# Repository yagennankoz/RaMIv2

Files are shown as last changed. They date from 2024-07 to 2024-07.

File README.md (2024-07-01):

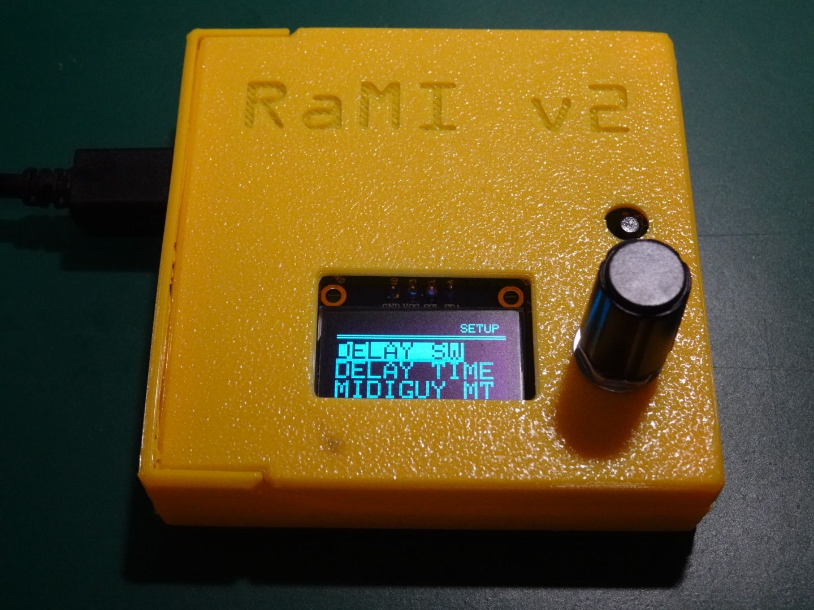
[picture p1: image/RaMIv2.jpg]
RaMI v2

# RaMI v2
X68000 Z MIDIインターフェイス<br>
MIDIタイミング遅延機能<br>
MIDI野郎 強制MT32音色機能付き<br>
<br>
<br>
### インストール方法
RaspberryPi picoのBOOTSELボタンを押しながらPCとUSB接続してください。<br>
Winの場合、エクスプローラで立ち上がってきますので、firmwareフォルダのfirmware.uf2をコピーしてください。<br>
ファイルのコピーが完了するとpicoが再起動します。<br>

### 操作方法
ロータリーエンコーダで選択および決定。タクトスイッチはキャンセルボタンです。<br>
決定/キャンセルボタン押下でメニューが表示されます。<br>
<br>
- DELAY SW
  - MIDI遅延のON/OFF
- DELAY TIME
  - MIDI遅延時間設定
- MIDIGUY MT
  - MIDI野郎音色のMT32互換モードON/OFF
- RESET
  - 設定の初期化

### 開発環境
- PlatformIO

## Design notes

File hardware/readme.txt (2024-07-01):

RaMI v2ボード  ver.0.2

回路図、ガーバー等のセットです。
一応お断りしておきますが、この回路を使用してX68000ZやRaspberryPi pico、MIDI音源等が破損しても当方は一切責任を負えませんのであらかじめご了承ください。

使用パーツは以下です。

・UART端子
	ターミナルブロック レセプタクル 2.54mm 3P
	[WJ15EDGRC-2.54-03P-140-00A]
	
	秋月電子
		https://akizukidenshi.com/catalog/g/gP-17009/

・ロータリーエンコーダ
	uxcell 360度ロータリーエンコーダ 7ピン 20桁 スイッチ付き
	
	Amazon
		https://www.amazon.co.jp/gp/product/B07RN3HB25/ref=ppx_yo_dt_b_asin_title_o08_s00

・3.5mm TRS
	3.5ｍｍ小型ステレオミニジャック 基板取付用

	秋月電子
		https://akizukidenshi.com/catalog/g/gC-02460/

・タクトスイッチ
	秋月電子
		https://akizukidenshi.com/catalog/g/gP-03646/

・OLED
	ピン配列がGND/VCC/SCL/SDAのSSD1306モジュール

	Amazon
		https://www.amazon.co.jp/gp/product/B08CDGTBCG/ref=ppx_yo_dt_b_asin_title_o03_s00

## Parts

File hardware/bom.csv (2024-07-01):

Designator | Footprint | Quantity | Value | LCSC Part #
Brd1 | 128x64OLED | 1 | SSD1306
C1, C2 | 0603 | 2 | 0.01u
J2 | Jack_3.5mm_Switronic_ST-005-G_horizontal | 1 | TRS
R1 | 0603 | 1 | 33 | C23140
R2 | 0603 | 1 | 10 | C22859
R3 | 0603 | 1 | 3.3k | C22978
R4, R5, R6, R7, R8 | 0603 | 5 | 10k | C25804
SW1 | RotaryEncoder_Alps_EC12E-Switch_Vertical_H20mm | 1 | RotaryEncoder_Switch
SW2 | SW_PUSH_6mm | 1 | SW_Push
U2 | RPi_Pico_SMD_TH | 1 | Pico
UART1 | WJ15EDGRC-2.54-03P-140-00A | 1 | ~

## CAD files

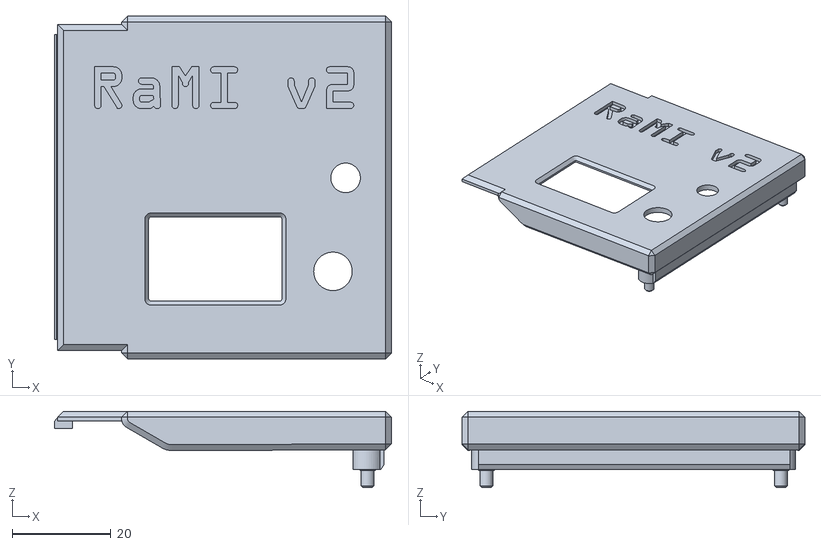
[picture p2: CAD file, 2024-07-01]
case/RaMI2_TOP.stl
68.3 x 69.5 x 15.5

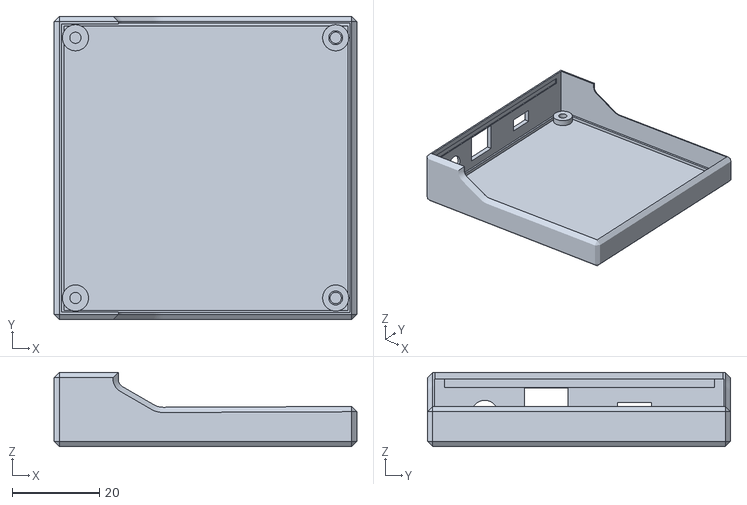
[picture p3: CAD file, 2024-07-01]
case/RaMI2_BOTTOM.stl
69.4 x 69.5 x 17.0

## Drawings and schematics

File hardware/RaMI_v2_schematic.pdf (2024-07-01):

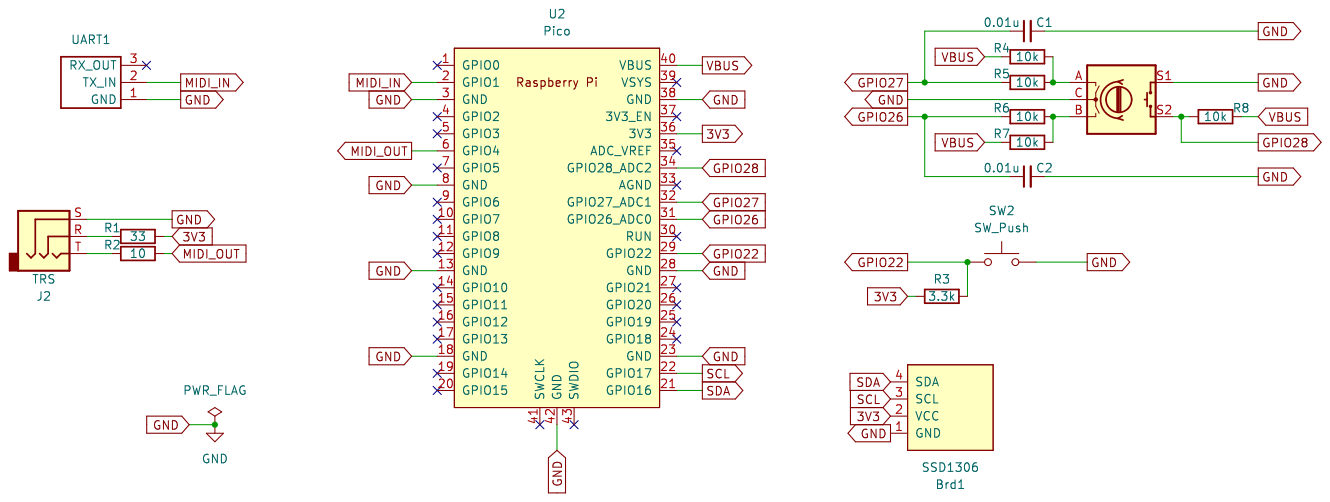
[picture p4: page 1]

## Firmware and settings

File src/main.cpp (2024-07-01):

#include <Arduino.h>

#include <stdio.h>
#include <string.h>
#include <hardware/uart.h>
#include <hardware/gpio.h>
#include <SPI.h>
#include <Wire.h>
#include <Adafruit_GFX.h>
#include <Adafruit_SSD1306.h>

#include "ModeBase.hpp"
#include "ModePlay.hpp"
#include "ModeConfig.hpp"
#include "ModeDelaySw.hpp"
#include "ModeDelayTime.hpp"
#include "ModeReset.hpp"
#include "ModeMidiGuy.hpp"
#include "util.hpp"
#include "rami.hpp"

static CONFIG_DATA config;
static note data_buffer[BUFFER_SIZE];
static uint16_t in_idx;
static uint16_t out_idx;
static uint8_t mode;
static uint16_t rotStateLast = 0;

Adafruit_SSD1306    oled(128, 64, &Wire, -1);
ModePlay            modePlay = ModePlay();
ModeConfig          modeConfig = ModeConfig();
ModeDelaySw         modeDelaySw = ModeDelaySw(&config);
ModeDelayTime       modeDelayTime = ModeDelayTime(&config);
ModeReset           modeReset = ModeReset(&config);
ModeMidiGuy         modeMidiGuy = ModeMidiGuy(&config);
int16_t             clk_last;

const int8_t KNOBDIR[] = {
   0, 0, 0, 0,
   0, 0, 0,-1,
   0, 0, 0, 1,
   0, 0, 0, 0};

static ModeBase *mode_tbl[] = {
    &modePlay,
    &modeConfig,
    &modeDelaySw,
    &modeDelayTime,
    &modeReset,
    &modeMidiGuy
};

void setup()
{
    Serial.begin(9600);

    Wire.setSDA(OLED_SDA_PIN);
    Wire.setSCL(OLED_SCL_PIN);
    Wire.begin(); 

    oled.begin(SSD1306_SWITCHCAPVCC, 0x3C);
    oled.setTextColor(SSD1306_WHITE);

    setup_gpio();

    load_setting(&config);
    in_idx = 0;
    out_idx = 0;

    mode = MODE_PLAY;

    modePlay.init();
    modePlay.setMsg("RaMI v2\r\n");

    oled.clearDisplay();
    oled.display();

    digitalWrite(LED_BUILTIN, LOW);
}

void loop() {
    uint32_t counter;
    uint32_t note_counter;
    uint32_t elapsed;
    uint32_t led_counter = 0;
    uint32_t led_elapsed;

    while (uart_is_writable(MIDI_OUT)) {
        mode_tbl[mode]->print(&oled);

        if (in_idx == out_idx) {
            digitalWrite(LED_BUILTIN, LOW);
            continue;
        }
        counter = time_us_32();
        note_counter = data_buffer[out_idx].counter;
        if (counter >= note_counter) {
            elapsed = counter - note_counter;
            led_elapsed = counter - led_counter;
        } else {
            elapsed = UINT32_MAX - note_counter + counter;
            led_elapsed = UINT32_MAX - led_counter + counter;
        }
        if (led_elapsed > 20000) {
            digitalWrite(LED_BUILTIN, LOW);
        }
        if (config.delay_enabled && (elapsed < config.delay_time)) {
            continue;
        }

        uart_putc_raw(MIDI_OUT, data_buffer[out_idx++].data);
        digitalWrite(LED_BUILTIN, HIGH);
        led_counter = counter;
        if (out_idx >= BUFFER_SIZE) {
            out_idx = 0;
        }
    }
    digitalWrite(LED_BUILTIN, LOW);
}

void setup_gpio() {
    pinMode(LED_BUILTIN, OUTPUT);
    digitalWrite(LED_BUILTIN, HIGH);

    gpio_set_function(UART0_RX_PIN, GPIO_FUNC_UART);
    gpio_set_function(UART1_TX_PIN, GPIO_FUNC_UART);

    uart_init(MIDI_IN, UART_BAUD_RATE);
    uart_set_hw_flow(MIDI_IN, false, false);
    uart_set_format(MIDI_IN, 8, 1, UART_PARITY_NONE);
    uart_set_fifo_enabled(MIDI_IN, false);
    int UART_IRQ = MIDI_IN == uart0 ? UART0_IRQ : UART1_IRQ;
    irq_set_exclusive_handler(UART_IRQ, midi_in_callback);
    irq_set_enabled(UART_IRQ, true);
    uart_set_irq_enables(MIDI_IN, true, false);

    uart_init(MIDI_OUT, UART_BAUD_RATE);
    uart_set_hw_flow(MIDI_OUT, false, false);
    uart_set_format(MIDI_OUT, 8, 1, UART_PARITY_NONE);
    uart_set_fifo_enabled(MIDI_OUT, false);

    pinMode(CANCEL_PIN, INPUT);
    attachInterrupt(CANCEL_PIN, cancel_callback, RISING);

    pinMode(OK_PIN, INPUT);
    attachInterrupt(OK_PIN, ok_callback, RISING);

    pinMode(ROT_A_PIN, INPUT);
    attachInterrupt(ROT_A_PIN, rotary_callback, CHANGE);
    pinMode(ROT_B_PIN, INPUT);
    attachInterrupt(ROT_B_PIN, rotary_callback, CHANGE);
}

static void midi_in_callback() {
    uint8_t c;
    while (uart_is_readable(MIDI_IN)) {
        c = uart_getc(MIDI_IN);
        if (config.midi_guy_mt_enabled && (c >= 0xC0 && c <= 0xCF)) {
            data_buffer[in_idx].data = (c & 0x0F) | 0xB0;
            data_buffer[in_idx++].counter = time_us_32();
            data_buffer[in_idx].data = 0x00;
            data_buffer[in_idx++].counter = time_us_32();
            data_buffer[in_idx].data = 0x7F;
            data_buffer[in_idx++].counter = time_us_32();
        }
        data_buffer[in_idx].data = c;
        data_buffer[in_idx++].counter = time_us_32();
        if (in_idx >= BUFFER_SIZE) {
            in_idx = 0;
        }
    }
}

static void cancel_callback()
{
    if (!isEventAvailable()) {
        return;
    }
    uint8_t mode_next = mode_tbl[mode]->onCancel();
    if (mode != mode_next) {
        mode = mode_next;
        mode_tbl[mode]->init();
    }
}

static void ok_callback()
{
    if (!isEventAvailable()) {
        return;
    }
    uint8_t mode_next = mode_tbl[mode]->onOK();
    if (mode != mode_next) {
        mode = mode_next;
        mode_tbl[mode]->init();
    }
}

static void rotary_callback()
{
    int8_t rot = 0;
    uint16_t nowState = digitalRead(ROT_A_PIN) | (digitalRead(ROT_B_PIN) << 1);
    rot = KNOBDIR[nowState | (rotStateLast << 2)];
    rotStateLast = nowState;

    mode_tbl[mode]->onRotate(rot);
}

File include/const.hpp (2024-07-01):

#ifndef _CONST_HPP_
#define _CONST_HPP_

#define UART0_TX_PIN        (0u)
#define UART0_RX_PIN        (1u)
#define UART1_TX_PIN        (4u)
#define UART1_RX_PIN        (5u)

// CANCEL BUTTON (GPIO22)
#define CANCEL_PIN          (22u)

// OK BUTTON (GPIO28)
#define OK_PIN              (28u)

// ROTARY ENCODER
// CLK (GPIO27)
#define ROT_A_PIN           (27u)
// DT (GPIO26)
#define ROT_B_PIN           (26u)

// SSD1306
// SDA
#define OLED_SDA_PIN        (16u)
// SCL
#define OLED_SCL_PIN        (17u)


#define MIDI_IN                     uart0
#define MIDI_OUT                    uart1

#define UART_BAUD_RATE              31250

#define BUFFER_SIZE                 2048 
#define FLASH_TARGET_OFFSET         0x1F0000
#define DELAY_TIME_DEFAULT          115000
#define DELAY_TIME_MAX              1000000
#define DELAY_DIFF                  500
#define EVENT_INTERVAL              (500000u)

#define COL_MAX                     (10u)
#define ROW_MAX                     (6u)

#define ENCODER_CLK_COUNT           (2u)

enum {
    MODE_PLAY,
    MODE_CONFIG,
    MODE_DELAY_SW,
    MODE_DELAY_TIME,
    MODE_RESET,
    MODE_MIDIGUY
};

typedef struct {
    uint32_t delay_time;
    uint8_t delay_enabled;
    uint8_t midi_guy_mt_enabled;
} CONFIG_DATA;

const uint8_t SIGNATURE[] = "RaMI";

#endif
